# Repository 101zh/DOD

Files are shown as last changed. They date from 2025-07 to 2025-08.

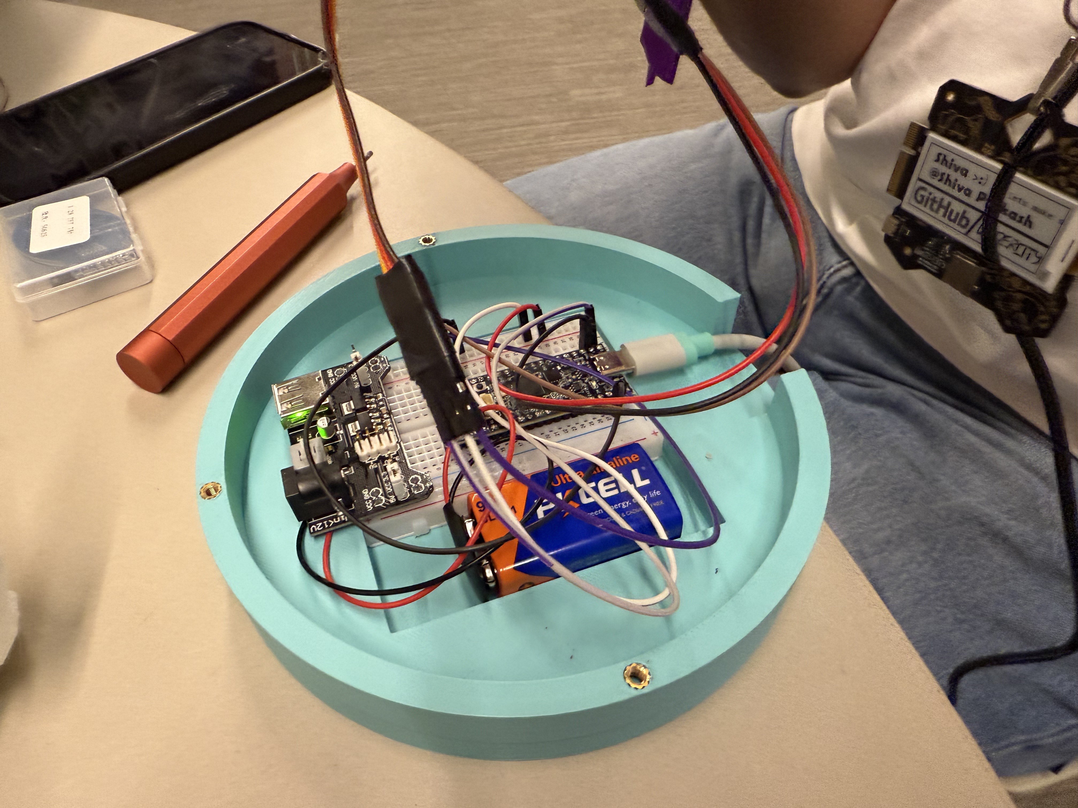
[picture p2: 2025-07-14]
pictures/IMG_4680.jpeg

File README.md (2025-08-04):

# Duck Off Doomscrolling

https://github.com/user-attachments/assets/c3fc7ac2-ea54-4331-85b3-b257e8ffefa3



https://www.youtube.com/watch?v=_19QPQVmDLk

## Project Overview

This project was made as a part of [Highway Undercity](https://highway.hackclub.com), a 4 day in person Hackathon hosted by [Hack Club](https://hackclub.com) and Github. 

Duck off Doomscrolling (or D.O.B for short) is a fun way to quit destructive/disruptive/depressing social media! Basically it is a duck that will sit on your desk while you work and squirt water on you if you open doom scrolling apps such as Instagram Reels, Youtube shorts, X, or whatever you want. 

** LETS QUIT DOOMSCROLLING :D **

## Technical Details

The base of the design is a cheap water gun powered by a servo motor, servo motors to pivot the duck towards the user, allowing for accuracy even in situations where the user is moving. The position of the user is attained using an hd webcam running OpenCV for facetracking. The base of doomscrolling detection is Apple Shortcuts, which ping a webserver whenever a non-desired app is opened.

## BOM

| Quantity | Name | Description | Source |
|---|---|---|---|
| 3 | MG 996R Servo Motor | Used for trigger, pitch and yaw control | |
| 1 | Orpheus Pico | Used for servo control, Hack Club version of Raspberry Pi Pico | |
| 1 | Water Pistol | Used for shooting water, disassembled to basic components | https://www.target.com/p/tidal-storm-hydro-storm-5pk/-/A-91989016#lnk=sametab |
| 1 | Breadboard | Used for Circuit connections, could use perfboard instead | |
| 1 | Breadboard Power Supply | Powers 5V to servos from the 9V battery, any Buck Converter works | |
| 1 | 9V battery | Powers the servos | |
| ~10 | Jumper Cables | Circuit connections | |
| 1 | HD Webcam | Used for face tracking | |
| 6 | 3D Printed Parts | Packaging/Mounting | |
| 10 | Hot Glue Sticks | Mounting and sealing | |
| Idk | M3 screws | For servo mounting and other | |
| Idk | M3 Heatset Inserts | Fort servo mounting and other | |

## Electrical Components

There are three servos, a breaboard, breadboard power supply, 9V battery, and an orpheus pico :D



## Duck Internals







## Code Details

First the camera captures video, which the computer processes to draw a box around a face via OPENCV. Then the computer tells the pico over serial what angle the servos should be at to center the midpoint of the box at the center of the screen/webcam feed. Through that info, the pico will then directly command the servos to move. The duck knows when to shoot via a web server, which can receive web hooks that the phone triggers over local wifi networks. When it is told to shoot it triggers a servo to push down on the pump to shoot the water >:D

## Code Changes Needed if you try this yourself!

The video capture feed may need to be changed, depending on the order of webcams connected to the device

```python
capture = cv2.VideoCapture(1)
```

The COM port may need to be changed, depending on the COM port that the orpheus pico is on.

```python
pico = serial.Serial('COM8', 115200)
```

For the two shortcut iphone automations (sorry android users; you're going to have to find a different way...), you'll need to change the IP address of the web server that when you send the HTTP GET request to.\
[https://www.icloud.com/shortcuts32e442381f65458999b183d71369fe7c](https://www.icloud.com/shortcuts32e442381f65458999b183d71369fe7c)\
[https://www.icloud.com/shortcuts/f4db4c2699c545bbb66151e4c6e04d96](https://www.icloud.com/shortcuts/f4db4c2699c545bbb66151e4c6e04d96)

### QR Codes for Shortcuts

lock-in
lock-out

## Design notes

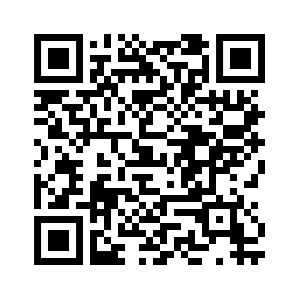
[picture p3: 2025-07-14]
pictures/lock-in.png

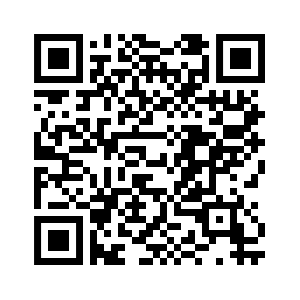
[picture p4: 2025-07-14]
pictures/lock-out.png

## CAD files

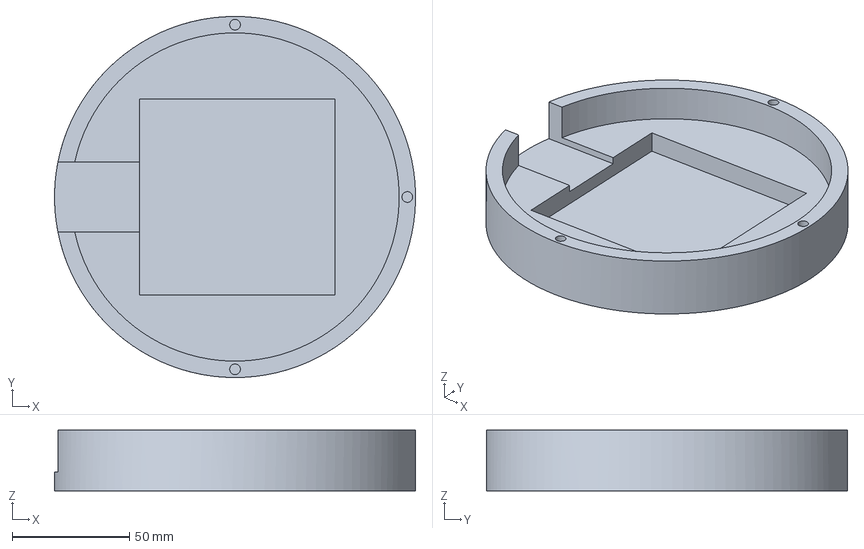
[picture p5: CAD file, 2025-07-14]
CAD/Base.3mf
154.0 x 154.0 x 26.0 mm

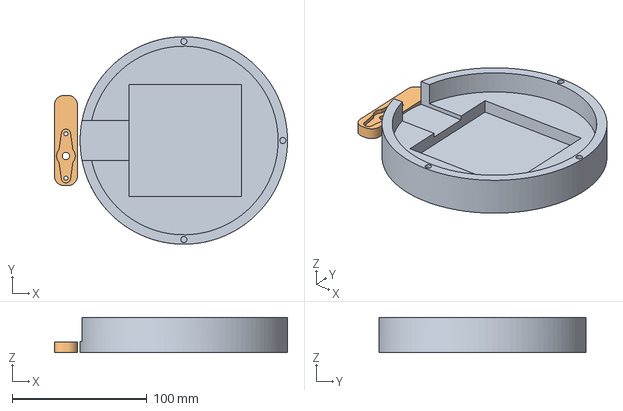
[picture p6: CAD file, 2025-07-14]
CAD/Servo Horn.3mf
173.0 x 154.0 x 26.0 mm
Base
Servo Horn

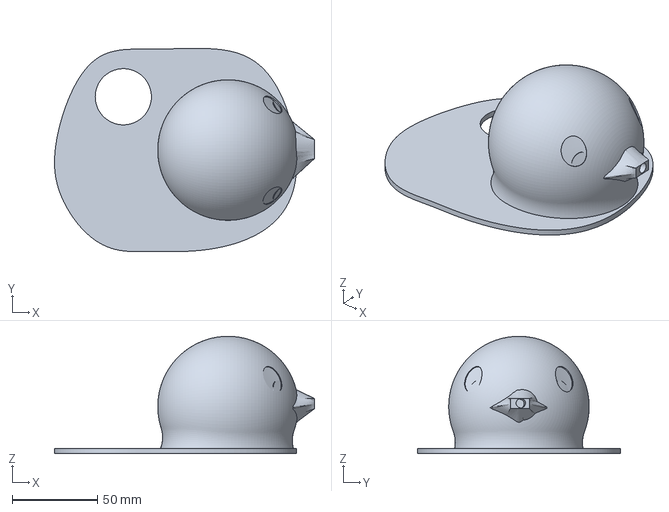
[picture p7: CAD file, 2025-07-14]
CAD/Top.3mf
152.7 x 119.3 x 68.9 mm

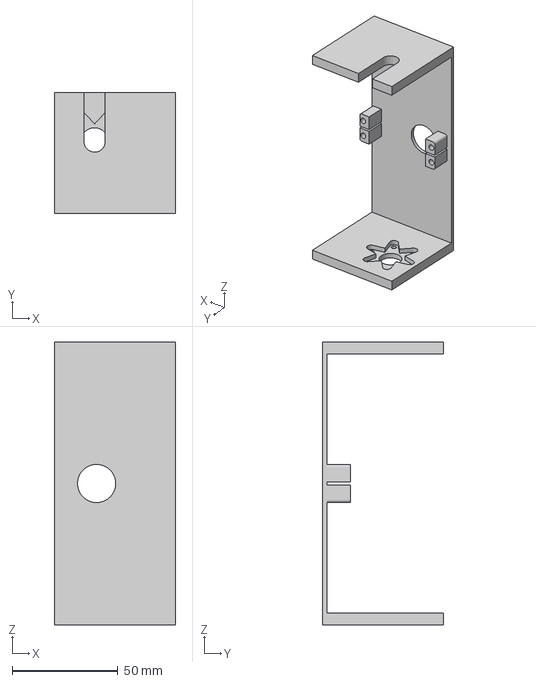
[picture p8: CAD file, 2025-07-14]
CAD/Bottom Frame.3mf
57.2 x 57.0 x 133.5 mm

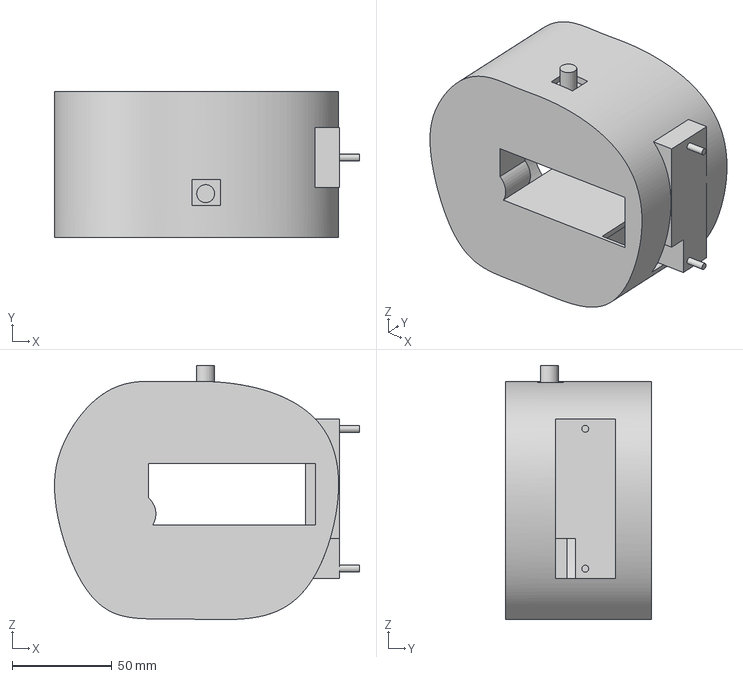
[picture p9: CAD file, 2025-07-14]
CAD/Bottom Case.3mf
152.7 x 73.0 x 127.3 mm

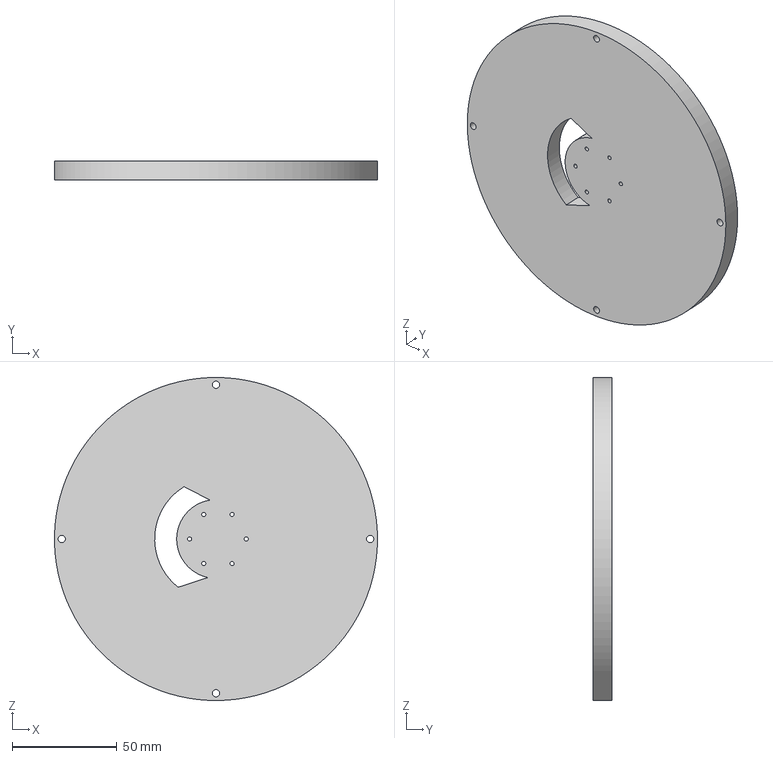
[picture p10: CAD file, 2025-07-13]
CAD/Cap.3mf
154.0 x 9.00 x 154.0 mm

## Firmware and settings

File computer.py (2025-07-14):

import cv2
import dlib
import serial
import time
from p_controller import PController

off_task: bool = False

controller: PController = PController(0.015, 15)
SET_POINT: float = 160
last_servo_angle: float = 90
scanning_up: bool = True

# Define the function to connect to Raspberry Pi Pico


def connect_pico():
    while True:
        try:
            # Find your Pico's COM port (check Device Manager on Windows)
            # Adjust COM port as necessary
            pico = serial.Serial('COM8', 115200)
            time.sleep(2)  # Give time for connection to establish
            print("Connected to Raspberry Pi Pico")
            return pico
        except serial.SerialException:
            print("Failed to connect to Pico. Retrying in 5 seconds...")
            time.sleep(5)


def pico_scan(pico: serial.Serial):
    global scanning_up
    global last_servo_angle

    servo_angle = (last_servo_angle + 1) if scanning_up else (last_servo_angle - 1)

    servo_angle = round(max(0, min(180, servo_angle)), 1)
    command = f"~b{servo_angle}\n"
    pico.write(command.encode())
    last_servo_angle = servo_angle

    if servo_angle >= 180:
        scanning_up = False
    elif servo_angle <= 0:
        scanning_up = True


# Function to send X coordinate to Pico


def send_x_coordinate_to_pico(pico, x, frame_width):
    global last_servo_angle
    try:
        output, at_setpoint = controller.update(SET_POINT, x)
        # Convert X coordinate to servo angle (0-180 degrees)
        # Map X position (0 to frame_width) to servo angle (0 to 180)
        servo_angle = last_servo_angle + output

        # Clamp to valid servo range
        servo_angle = round(max(0, min(180, servo_angle)), 1)

        # Send angle to Pico
        command = f"~b{servo_angle}\n"
        pico.write(command.encode())
        # print(f"Sent X: {x} -> Servo Angle: {servo_angle}")
        last_servo_angle = servo_angle
    except serial.SerialException:
        print("Lost connection to Pico. Attempting to reconnect...")
        pico.close()
        pico = connect_pico()


# Initialize face cascade and parameters
faceCascade = cv2.CascadeClassifier(
    cv2.data.haarcascades + 'haarcascade_frontalface_default.xml')
OUTPUT_SIZE_WIDTH = 775
OUTPUT_SIZE_HEIGHT = 600


def detectAndTrackLargestFace():
    # Set camera index to 0 for the built-in webcam
    capture = cv2.VideoCapture(1)
    cv2.namedWindow("base-image", cv2.WINDOW_AUTOSIZE)
    cv2.namedWindow("result-image", cv2.WINDOW_AUTOSIZE)
    cv2.moveWindow("base-image", 0, 100)
    cv2.moveWindow("result-image", 400, 100)
    cv2.startWindowThread()

    tracker = dlib.correlation_tracker()
    trackingFace = 0
    rectangleColor = (0, 165, 255)

    pico = connect_pico()  # Initialize Pico connection

    try:
        while True:
            global off_task
            with open("shared.info.txt", "r") as file:
                info: str = file.read()
                if info == "True" and (not off_task):
                    off_task = True
                    pico.write("~s\n".encode())
                elif info == "False" and (off_task):
                    off_task = False

            if pico.in_waiting > 0:
                response = pico.readline().decode().strip()
                print(f"Pico responded: {response}")

            rc, fullSizeBaseImage = capture.read()
            baseImage = cv2.resize(fullSizeBaseImage, (320, 240))
            frame_width = baseImage.shape[1]  # Get frame width for mapping

            pressedKey = cv2.waitKey(2)
            if pressedKey == ord('Q'):
                cv2.destroyAllWindows()
                exit(0)

            resultImage = baseImage.copy()

            if not trackingFace:
                gray = cv2.cvtColor(baseImage, cv2.COLOR_BGR2GRAY)
                faces = faceCascade.detectMultiScale(gray, 1.3, 5)
                # print("Using the cascade detector to detect face")

                maxArea = 0
                x, y, w, h = 0, 0, 0, 0

                for (_x, _y, _w, _h) in faces:
                    if _w * _h > maxArea:
                        x, y, w, h = int(_x), int(_y), int(_w), int(_h)
                        maxArea = w * h

                if maxArea > 0:
                    tracker.start_track(baseImage,
                                        dlib.rectangle(x - 10,
                                                       y - 20,
                                                       x + w + 10,
                                                       y + h + 20))
                    trackingFace = 1

            if trackingFace:
                trackingQuality = tracker.update(baseImage)

                if trackingQuality >= 8.75:
                    tracked_position = tracker.get_position()
                    t_x = int(tracked_position.left())
                    t_y = int(tracked_position.top())
                    t_w = int(tracked_position.width())
                    t_h = int(tracked_position.height())
                    cv2.rectangle(resultImage, (t_x, t_y),
                                  (t_x + t_w, t_y + t_h),
                                  rectangleColor, 2)

                    # Calculate center X position (ignore Y for horizontal tracking)
                    cX = int((t_x + t_x + t_w) / 2)
                    cY = int((t_y + t_y + t_h) / 2)
                    cv2.circle(resultImage, (cX, cY), 1, (0, 0, 255), -1)

                    # Draw "TARGET LOCKED" in red under the bounding box
                    font = cv2.FONT_HERSHEY_PLAIN
                    text_position = (t_x, t_y + t_h + 30)
                    cv2.putText(resultImage, "TARGET LOCKED",
                                text_position, font, 1, (0, 0, 255), 2, cv2.LINE_AA)

                    send_x_coordinate_to_pico(pico, cX, frame_width)

                else:
                    trackingFace = 0

            else:
                pico_scan(pico)

            largeResult = cv2.resize(
                resultImage, (OUTPUT_SIZE_WIDTH, OUTPUT_SIZE_HEIGHT))
            cv2.imshow("base-image", baseImage)
            cv2.imshow("result-image", largeResult)

    except KeyboardInterrupt as e:
        print(e.args)
        cv2.destroyAllWindows()
        pico.close()
        exit(0)


if __name__ == '__main__':
    detectAndTrackLargestFace()

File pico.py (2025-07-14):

import select
import time
import board
import pwmio
import sys
import gc
from adafruit_motor import servo

can_shoot : bool = False

class DOD_servo:
    def __init__(self, pin, duty_cycle: int, frequency: int):
        self = self
        self.servo = servo.Servo(pwmio.PWMOut(
            pin, duty_cycle=duty_cycle, frequency=frequency))
        self.current_angle = 90
        self.target_angle = 90
        self.running_to_target = False

    def set_target_angle(self, angle_serial_input):
        if self.running_to_target:
            return
        
        print(angle_serial_input)
        new_target = ""

        for char in angle_serial_input:
            new_target += char

        print(new_target)
        self.target_angle = float(new_target)

    def run_to_target_angle(self):
            self.running_to_target = True
            if self.current_angle < self.target_angle:
                # 0 - 180 degrees, 5 degrees at a time.
                for angle in range(self.current_angle, self.target_angle, 1):
                    self.servo.angle = angle
                    self.current_angle = angle
                    time.sleep(0.01)
            elif self.current_angle > self.target_angle:
                # 180 - 0 degrees, 5 degrees at a time.
                for angle in range(self.current_angle, self.target_angle, -1):
                    self.servo.angle = angle
                    self.current_angle = angle
                    time.sleep(0.01)

            self.running_to_target = False

    def run_to_target_angle_fast(self):
        self.servo.angle = self.target_angle

base_servo : DOD_servo = DOD_servo(board.GP0, 2**15, 50)
trigger_servo : DOD_servo = DOD_servo(board.GP1, 2**15, 50)

buffered_input = []

def read_serial_input():
    select_result = select.select([sys.stdin], [], [], 0)
    while select_result[0]:
        input_character = sys.stdin.read(1)
        print(f"Received: {repr(input_character)}")

        if (input_character == "\n"):
            print(buffered_input)
            determine_action(buffered_input)
            buffered_input.clear()
        else:
            buffered_input.append(input_character)

        select_result = select.select([sys.stdin], [], [], 0)

def remove_tags(serial_input: list):
    serial_input.pop(0)
    serial_input.pop(0)

def determine_action(serial_input: list):
    global can_shoot

    tag: str = serial_input[0] + serial_input[1]
    remove_tags(serial_input)

    if (tag == "~b"):
        base_servo.set_target_angle(serial_input)
    elif(tag == "~s"):
        shoot()
    elif(tag == "~r"):
        trigger_servo.set_target_angle(serial_input)

def shoot():
    trigger_servo.set_target_angle(["1","3","5"])
    trigger_servo.run_to_target_angle_fast()
    time.sleep(1)
    trigger_servo.set_target_angle(["8","9"])
    trigger_servo.run_to_target_angle_fast()
    time.sleep(1)

while True:
    base_servo.run_to_target_angle()
    trigger_servo.run_to_target_angle()
    read_serial_input()

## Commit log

2025-07-12 add code for the pico
2025-07-13 fix crashing problem by nuking pico
    [computer.py, pico.py, webhook.py]
2025-07-13 prototype trigger servo
2025-07-14 add final CAD
